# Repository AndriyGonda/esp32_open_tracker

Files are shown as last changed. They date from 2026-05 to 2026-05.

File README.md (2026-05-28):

# ESP Open Tracker

An open-source GPS tracker built on the ESP32-C3 microcontroller, designed for real-time vehicle or asset tracking via the OsmAnd protocol.

## Features

- **Real-time GPS tracking** — sends location data to any OsmAnd-compatible server (e.g. m2m.eu,  Traccar)
- **Adaptive send interval** — adjusts automatically based on movement:
  - Stationary: every 30 seconds
  - Moving: every 10 seconds
  - Turning (>7°): every 2 seconds
- **Black box** — stores track points to LittleFS flash when offline, automatically uploads when connection is restored
- **Battery monitoring** — measures voltage via ADC with resistor divider, sends battery level with each packet
- **Power management** — low battery warning via buzzer, deep sleep on critical battery level (<2.9V)
- **Filtering zone** — replaces real coordinates with home location if coordinates outside of a configurable radius to handle gps spoofing
- **Wi-Fi manager** — web-based configuration portal (AP mode) for managing Wi-Fi networks and server settings
- **Auto reconnect** — automatically reconnects to saved Wi-Fi networks in the background
- **LED indicators** — non-blocking LED feedback for Wi-Fi connection and successful data transmission
- **Buzzer alerts** — audio feedback on Wi-Fi connect and low battery

## Hardware

- **MCU**: ESP32-C3 Super Mini
- **GPS**: GP-02 (NMEA, 9600 baud, UART on GPIO3/GPIO4)
- **Battery**: Li-ion, monitored via voltage divider on GPIO1
- **Buzzer**: Passive buzzer on GPIO5
- **Button**: Long press on GPIO10 opens config portal

All key parameters are defined in `include/TrackerConfig.h`:

```cpp
#define TRACKER_DEVICE_ID        "esp-nav-001"
#define TRACKER_INTERVAL_STATIC  30000
#define TRACKER_INTERVAL_MOVING  10000
#define TRACKER_INTERVAL_TURNING 2000
#define TRACKER_SPEED_THRESHOLD  1.0f
#define TRACKER_BEARING_THRESHOLD 7.0f
#define TRACKER_HOME_LAT         49.123456
#define TRACKER_HOME_LNG         32.123456
#define TRACKER_HOME_RADIUS_KM   0.2f
```

## OsmAnd Protocol

Data is sent via HTTP GET to your server:

```
http://<host>:<port>/?id=<device_id>&lat=...&lon=...&timestamp=...
  &speed=...&bearing=...&altitude=...&hdop=...&satellites=...
  &batt=...&free_kb=...&distance=...
```

## Config Portal

Long press the button on GPIO10 to open the configuration portal:

- Connect to Wi-Fi AP: **ESP Nav** / password: **12345678**
- Open browser: **http://192.168.4.1**
- Add/remove Wi-Fi networks
- Set server host and port

## Dependencies

- [TinyGPS++](https://github.com/mikalhart/TinyGPSPlus)
- Arduino framework for ESP32 (PlatformIO)

## Schematic

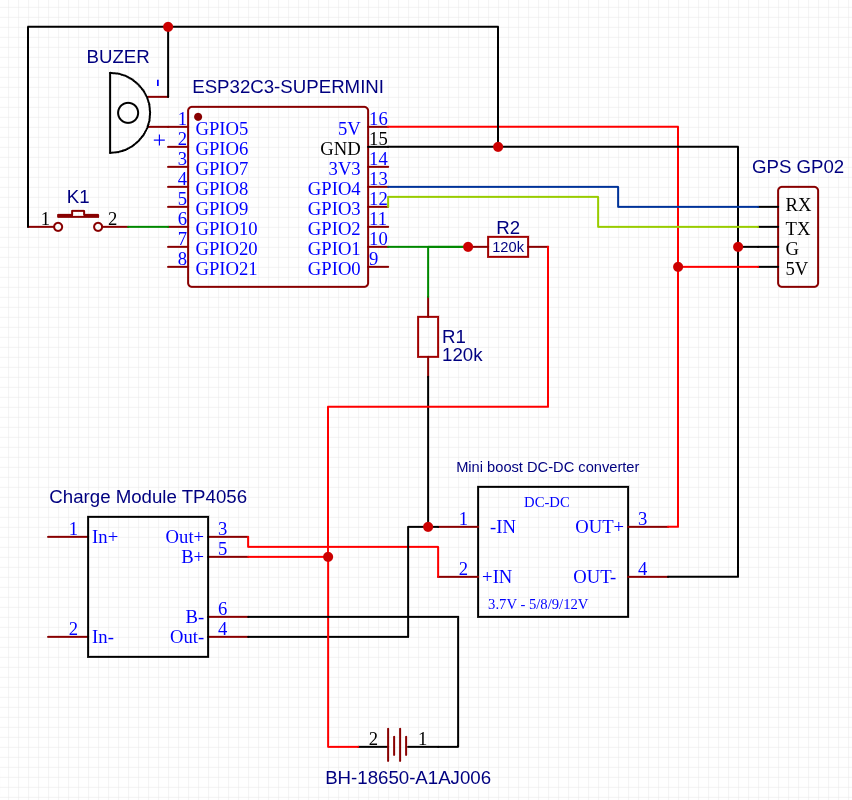
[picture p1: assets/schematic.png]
ESP Open Tracker


## Bill of Materials

| #  | Component | Qty | Notes |
| -- | --- | --- | --- |
| 1  | ESP32-C3 Super Mini | 1 | Main microcontroller |
| 2  | GP-02 GPS module | 1 | NMEA, 9600 baud |
| 3  | Resistor 120kΩ | 2  | Voltage divider |
| 4  | Passive buzzer | 1 | 3.3V compatible |
| 5  | Tactile push button | 1 | Config portal trigger |
| 6  | DC-DC boost converter (5V) | 1 | Powers GPS module |
| 7  | TP4056 charger module (USB-C) | 1 | Li-ion battery charging |
| 8  | 18650 Li-ion battery with pin | 1 | Main power source |
| 9 | 18650 battery holder | 1 | |
| 10 | Capacitor 100nF (or 220nF) | 1 | ADC noise filtering on GPIO1 |
| 11 | Perfboard 50×70mm | 1 | For soldering components |
| 12 | Jumper wires | —  | For connections |
| 13 | Knurled nuts M3 | 8  | For case and covers |
| 13 | Nut M3х10 | 8  | For case and covers |
| 13 | BMI160 | 1  | For more precisous position stationary or moving support (connects to i2c pins 6 and 7) |

## Assembly of the device

### Board assembly

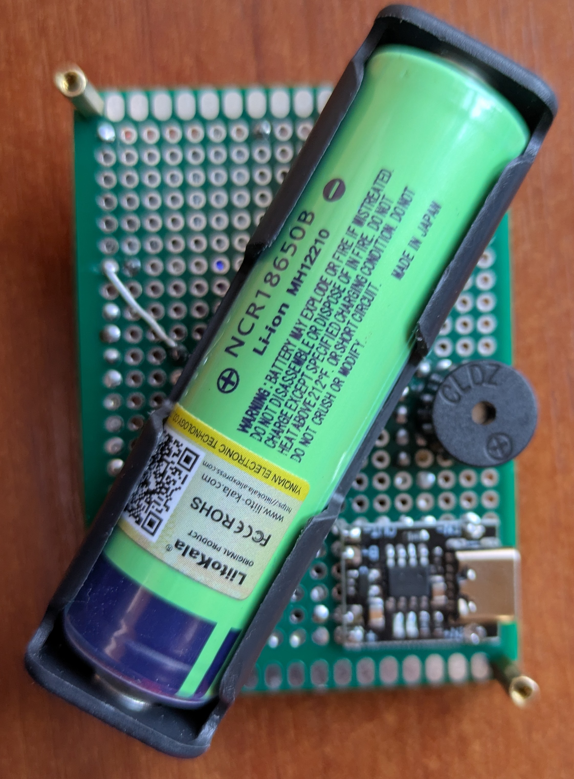
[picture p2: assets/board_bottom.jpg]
Board bottom


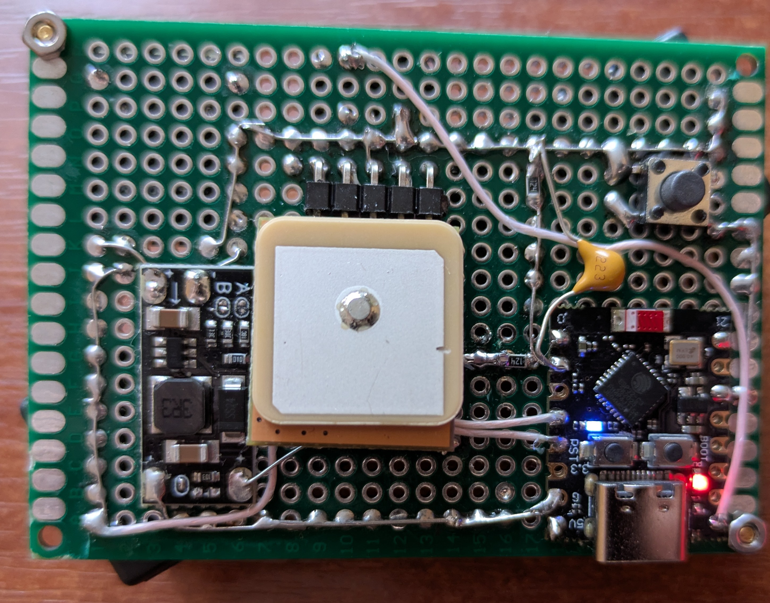
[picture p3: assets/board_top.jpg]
Board top


### Case with board assembly

Board top

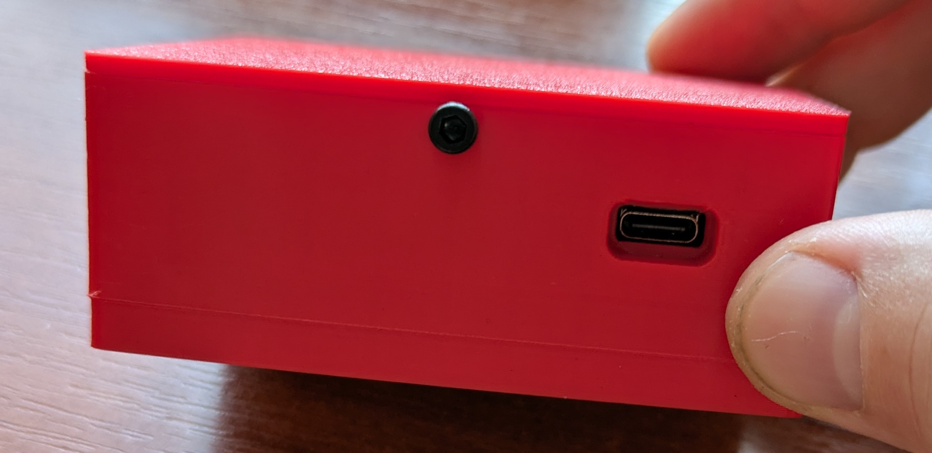
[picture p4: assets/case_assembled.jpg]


## 3D Printed Case

Print files are located in the `3d/` folder:

| File | Description |
|---|---|
| [`case_box_tracker.STL`](3d/case_box_tracker.STL) | Main enclosure body |
| [`case_lid.STL`](3d/case_lid.STL) | Enclosure lid |
| [`case_mount.STL`](3d/case_mount.STL) | Bottom lid (can be used as mount) |

## License

LGPL3

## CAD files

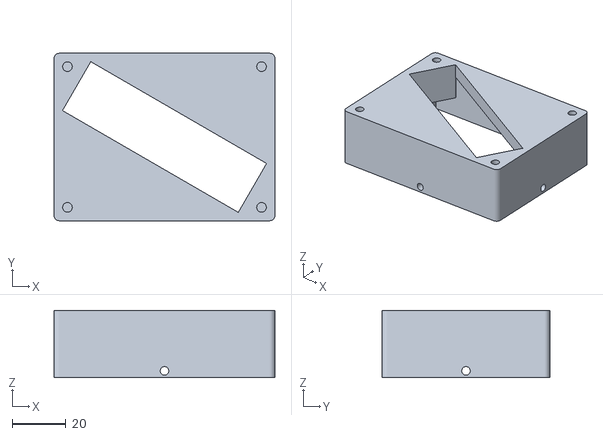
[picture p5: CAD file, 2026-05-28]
3d/case_box_tracker.STL
82.1 x 62.3 x 25.0

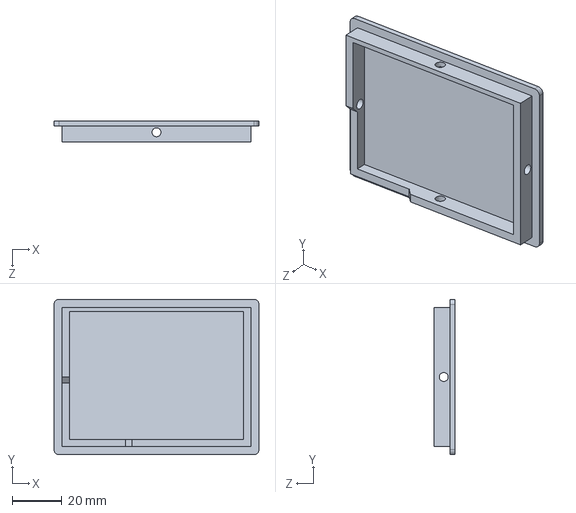
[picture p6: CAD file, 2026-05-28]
3d/source/case_lid.SLDPRT
82.1 x 62.3 x 8.40 mm

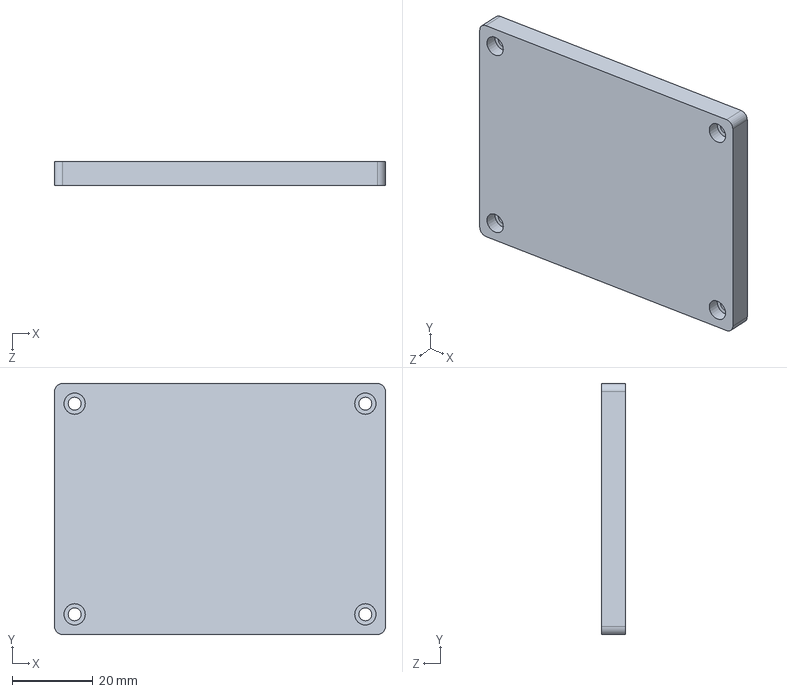
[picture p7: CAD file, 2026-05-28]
3d/source/case_mount.SLDPRT
82.1 x 62.3 x 6.00 mm

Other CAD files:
3d/source/case.SLDPRT
3d/case_lid.STL
3d/case_mount.STL

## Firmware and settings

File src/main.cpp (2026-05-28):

#include <Arduino.h>
#include <esp_task_wdt.h>
#include <esp_sleep.h>
#include "AppSettings.h"
#include "LedController.h"
#include "WifiConnector.h"
#include "ConfigPortal.h"
#include "ButtonHandler.h"
#include "BatteryMonitor.h"
#include "GpsReader.h"
#include "ImuReader.h"
#include "GpsPowerManager.h"
#include "Tracker.h"
#include "PowerManager.h"

#define BUTTON_PIN 10
#define LONG_PRESS_MS 3000

#ifndef LED_BUILTIN
#define LED_BUILTIN 8
#endif

AppSettings appSettings;
LedController ledController(LED_BUILTIN);
ConfigPortal configPortal(appSettings);
WifiConnector wifiConnector(appSettings, ledController, configPortal);
ButtonHandler buttonHandler(BUTTON_PIN, LONG_PRESS_MS);

BatteryMonitor batteryMonitor(1, 2.0f);
PowerManager powerManager(batteryMonitor);

GpsReader gpsReader(3, 4);
ImuReader imuReader(IMU_SDA_PIN, IMU_SCL_PIN);
GpsPowerManager gpsPowerManager(gpsReader, imuReader);
Tracker tracker(gpsReader, appSettings, batteryMonitor, configPortal, ledController);

static void printLoadedSettings() {
    Serial.println();
    Serial.println("=== Loaded settings ===");
    Serial.print("Server host: ");
    Serial.println(appSettings.getServerHost());
    Serial.print("Server port: ");
    Serial.println(appSettings.getServerPort());
    Serial.print("Saved WiFi count: ");
    Serial.println(appSettings.getWifiCount());

    for (uint8_t i = 0; i < appSettings.getWifiCount(); i++) {
        const auto& wifi = appSettings.getWifi(i);
        Serial.print("Saved SSID #");
        Serial.print(i + 1);
        Serial.print(": ");
        Serial.println(wifi.ssid);
        Serial.print("Saved password length: ");
        Serial.println(wifi.password.length());
    }

    Serial.println("=======================");
    Serial.println();
}

static void init_watchdog() {
    esp_task_wdt_config_t wdt_config = {
        .timeout_ms = 30000,
        .idle_core_mask = 0,
        .trigger_panic = true
    };
    esp_task_wdt_reconfigure(&wdt_config);
    esp_task_wdt_add(NULL);
}

void setup() {
    delay(300);
    pinMode(GPS_SLEEP_PIN, OUTPUT);
    digitalWrite(GPS_SLEEP_PIN, GPS_WAKE_ACTIVE_LEVEL);

    Serial.begin(115200);
    delay(300);

    esp_sleep_wakeup_cause_t cause = esp_sleep_get_wakeup_cause();
    if (cause == ESP_SLEEP_WAKEUP_GPIO) {
        Serial.println("[Boot] wakeup by IMU motion interrupt");
    } else if (cause == ESP_SLEEP_WAKEUP_TIMER) {
        Serial.println("[Boot] wakeup by timer");
    } else {
        Serial.println("[Boot] normal boot");
    }

    btStop();
    setCpuFrequencyMhz(80);

    ledController.begin();
    buttonHandler.begin();
    configPortal.begin();

    appSettings.load();
    printLoadedSettings();

    batteryMonitor.begin();
    powerManager.begin();

    gpsReader.begin();

    bool imuOk = false;
    for (uint8_t attempt = 1; attempt <= 3; attempt++) {
        Serial.printf("[Main] IMU init attempt %d/3\n", attempt);
        if (imuReader.begin()) {
            imuReader.setThreshold(IMU_ACCEL_THRESHOLD);
#ifdef IMU_INT_PIN
            imuReader.enableMotionInterrupt(IMU_INT_PIN);
#endif
            imuOk = true;
            break;
        }
        delay(1000);
    }
    if (!imuOk) {
        Serial.println("[Main] IMU init failed, GPS power manager will keep GPS awake");
    }

    gpsPowerManager.begin();

    WiFi.mode(WIFI_OFF);
    Serial.println("WiFi off at startup, Tracker will connect when needed");

    tracker.begin();
    init_watchdog();
}

void loop() {
    esp_task_wdt_reset();
    powerManager.update();

    if (!powerManager.isOperational()) {
        delay(10);
        return;
    }

    if (buttonHandler.isLongPressTriggered()) {
        if (!configPortal.isActive()) {
            Serial.println("Long press detected. Opening config portal...");
            tracker.forceReleaseWifi();
            configPortal.start();
        }
    }

    ledController.update();
    wifiConnector.update();
    configPortal.loop();
    batteryMonitor.update();
    imuReader.update();
    gpsPowerManager.update();
    gpsReader.update();
    tracker.update();

    delay(10);
}

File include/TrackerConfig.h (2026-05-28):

#pragma once

// OsmAnd device id (must be unique for navigation system like Traccar or M2M)
#define TRACKER_DEVICE_ID "11223344556"


// Max valid hdop for tracker
#define MAX_HDOP 10
#define MIN_SATELLITES 6

// Sending intervals
#define TRACKER_INTERVAL_STATIC   600000   // 10 minutes idle
#define TRACKER_INTERVAL_MOVING    10000   // moving
#define TRACKER_INTERVAL_TURNING    2000   // rotation

// Speed threshold in km/h
#define TRACKER_SPEED_THRESHOLD     4.0f
#define TRACKER_MAX_VALID_SPEED    100.0f  

// Bearing threshold in dec
#define TRACKER_BEARING_THRESHOLD   7.0f   


// Blackbox setup 
#define TRACKER_BLACKBOX_PATH       "/blackbox.csv"
#define TRACKER_BLACKBOX_MIN_FREE   51200 



/*HOME POINT FILTERING (Preventing gps spoofing) */
#define ENABLE_HOME_POINT_FILTERING true
#define TRACKER_HOME_LAT        49.439315 
#define TRACKER_HOME_LNG        32.006180 
#define TRACKER_HOME_RADIUS_KM   500.0f 

/*BATTERY MANAGEMENT */
#define BATTERY_LOW_VOLTAGE       3.5f
#define BATTERY_CRITICAL_VOLTAGE  3.0f

// Use home coordinates when battery is low and location is invalid
#define LOW_BATT_HOME_FALLBACK true

// WiFi power management
#define WIFI_TX_POWER             52       // TX_POWER * 0.25  dBm  (formula)
#define WIFI_RETRY_INTERVAL_MS    60000   // 2 min between retries after fail

// WiFi positioning via beacondb.net (requires WiFi connection)
#define ENABLE_WIFI_POSITIONING false

#define ENABLE_PARKING_FILTER         true

// --- Position pinning ---
// Seconds the device must remain stationary before the anchor is set.
#define PARKING_PIN_DELAY_SEC         60

// Maximum drift (meters) allowed while pinned.
#define PARKING_PIN_RADIUS_M          30.0f


// --- Motion consensus (sliding window) ---
// How many consecutive GPS readings to keep in the window.
#define PARKING_WINDOW_SIZE           6


// before the tracker accepts "moving" state.
#define PARKING_MOTION_MIN_MOVING     3
#define PARKING_MAX_ACCELERATION  3.5f 


// ---- GPS power management ----
#define GPS_SLEEP_PIN                  2
#define GPS_SLEEP_ACTIVE_LEVEL         LOW
#define GPS_WAKE_ACTIVE_LEVEL          HIGH
#define GPS_WAKE_SETTLE_MS             5000UL
#define GPS_STALE_DATA_MS              3000UL
#define GPS_MIN_AWAKE_AFTER_WAKE_MS    700000UL
#define GPS_SLEEP_AFTER_IMU_STILL_MS   700000UL

// ---- IMU (BMI160) motion assist ----
#define ENABLE_IMU                    true

// I2C pins: SDA -> GPIO6, SCL -> GPIO7
#define IMU_SDA_PIN                   6
#define IMU_SCL_PIN                   7


#define IMU_ACCEL_THRESHOLD           0.3f

// Motion fusion strategy:
//   FUSION_AND – moving if GPS AND IMU agree  (most reliable, default)
//   FUSION_OR  – moving if GPS OR  IMU detect motion  (most sensitive)
//   FUSION_IMU – IMU only, ignore GPS speed  (for testing)
#define IMU_FUSION_STRATEGY           FUSION_AND

//#define IMU_INT_PIN  2 TODO: need fix on hardware level

// TODO: temporary disabled. Need hardware fix
// How long the device must be stationary before sleep is considered (ms)
// 1 minutes = 6000000
#define PARKING_SLEEP_DELAY_MS      600000UL


// How long to sleep when stationary (ms)
// 1 minutes = 60000 (make it minimal for esp32 c3)
#define PARKING_SLEEP_DURATION_MS   60000UL

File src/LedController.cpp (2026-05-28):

#include "LedController.h"

LedController::LedController(uint8_t pin) : pin(pin) {
}

void LedController::begin() {
    pinMode(pin, OUTPUT);
    digitalWrite(pin, HIGH);
    blinkTotal = 0;
    blinkCount = 0;
    blinkState = false;
}

void LedController::on() {
    blinkTotal = 0;
    blinkCount = 0;
    blinkState = false;
    digitalWrite(pin, LOW);
}

void LedController::off() {
    blinkTotal = 0;
    blinkCount = 0;
    blinkState = false;
    digitalWrite(pin, HIGH);
}

void LedController::blink(uint8_t times, uint16_t onMs, uint16_t offMs) {
    blinkTotal   = times;
    blinkCount   = 0;
    blinkOnMs    = onMs;
    blinkOffMs   = offMs;
    blinkState   = false;
    lastToggleAt = millis();
    digitalWrite(pin, HIGH);
}

void LedController::update() {
    if (blinkTotal == 0) return;

    if (blinkCount >= blinkTotal) {
        digitalWrite(pin, HIGH);
        blinkTotal = 0;
        blinkCount = 0;
        blinkState = false;
        return;
    }

    unsigned long now = millis();
    uint16_t interval = blinkState ? blinkOnMs : blinkOffMs;

    if (now - lastToggleAt < interval) return;

    lastToggleAt = now;
    blinkState = !blinkState;
    digitalWrite(pin, blinkState ? LOW : HIGH);

    if (!blinkState) {
        blinkCount++;
    }
}
